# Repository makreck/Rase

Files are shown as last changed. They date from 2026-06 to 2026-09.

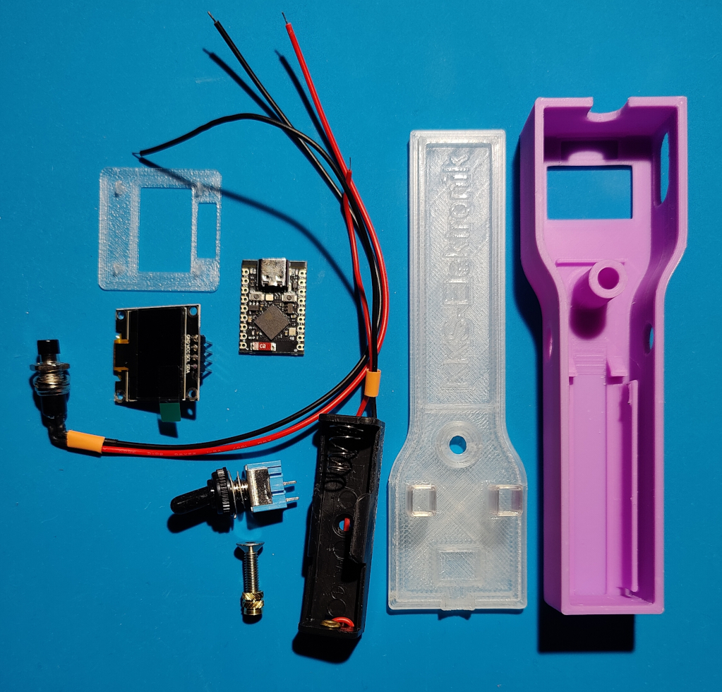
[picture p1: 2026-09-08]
images/probe/Type_C/Housings_Rev_C_Material_2.jpg

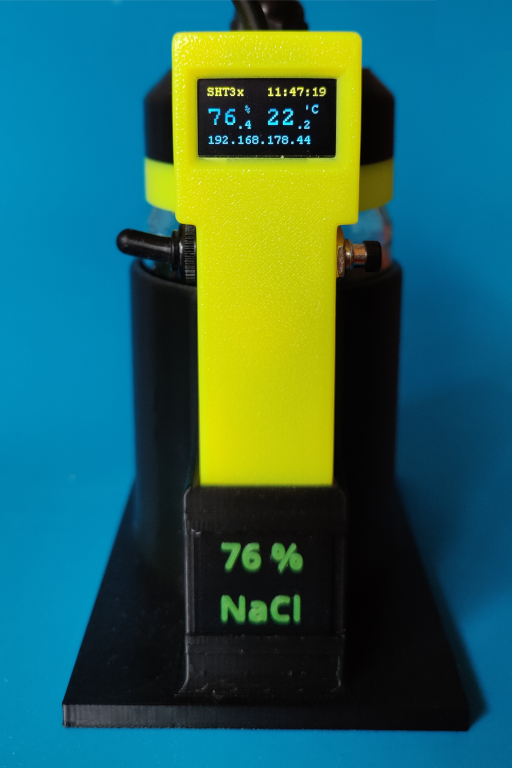
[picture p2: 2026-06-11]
images/calibration/Deliquescence_humidity_container_NaCl_76.png

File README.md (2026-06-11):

# Rase
## A Radio Sensor Project

### Disclaimer of Liability

This project is licensed under the terms of the GNU General Public License, version 3 or later (the "License"). A copy of the license is included in the root directory of this repository, and can also be found at "https://www.gnu.org/licenses/gpl-3.0.en.html".

This project is provided "as is", as open-source software and hardware, and is intended for hobbyist and enthusiast use, without warranties of any kind, either express or implied. The authors and contributors disclaim all liability for any damages or losses arising from the use or inability to use this project, including but not limited to direct, indirect, incidental, special, or consequential damages.

You are solely responsible for:
- Ensuring compliance with local laws and regulations when using this project.
- Any modifications or adaptations made to the hardware, firmware, or software.
- The safe and proper operation of any devices built using this project.
- Compliance with applicable licensing terms (e.g., GPL, MIT).

No warranties are given regarding:
- The accuracy, reliability, or suitability of the project for any purpose.
- The absence of errors or defects in the code, documentation, or hardware designs.
- Compatibility with third-party software or hardware.
- Build guides and documentation are provided for informational purposes. The authors do not guarantee correctness, completeness, or suitability for any specific purpose.

By using this project, you acknowledge and agree to these terms.

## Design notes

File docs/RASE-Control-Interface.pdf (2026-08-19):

# RASE Sensor Control Interface

## RESTful interface, endpoints over HTTP:

"/" | HTTP GET | Root website.
"/config" | HTTP GET | Configuration website.
"/update" | HTTP GET | Update website.
"/favicon.ico" | HTTP GET | Favicon request.
"/api/sensors" | HTTP GET | Query currently sensor status, returns JSON string.
"/api/id" | HTTP GET | Query device identifivation, returns JSON string.
"/api/config" | HTTP GET HTTP PUT | Query device configuration, return JSON string. Write device configuration, writes back JSON string.
"/api/reboot" | HTTP GET | Causes device reboot. Returns status JSON string.
"/api/update" | HTTP PUT | Receives new firmware image (binary).

## Terminal interface, endpoints over TTY:

"/root" | Returns HTTP source of root website.
"/connect" | Configures WiFi conection, format: „/connect=Wifi-SSID:password“
"/broker" | Configures MQTT broker, format: /broker=IP-addr[:username[:password]]“
"/par" | Set a single config parameter. Allowed keys are all keys of config JSON string. Format: „/par=key:value“
"/api/sensors" | Query currently sensor status, returns JSON string.
"/api/id" | Query device identifivation, returns JSON string.
"/api/config" | Query device configuration, return JSON string.
„/api/config=“ | Write device configuration, writes back JSON string. Parameter = config JSON.
"/api/reboot" | Forces an immediate device reboot.
"/api/initialize" | Forces a factory init. All condfig parameter are set to their defaults.

## Root website layout (example):

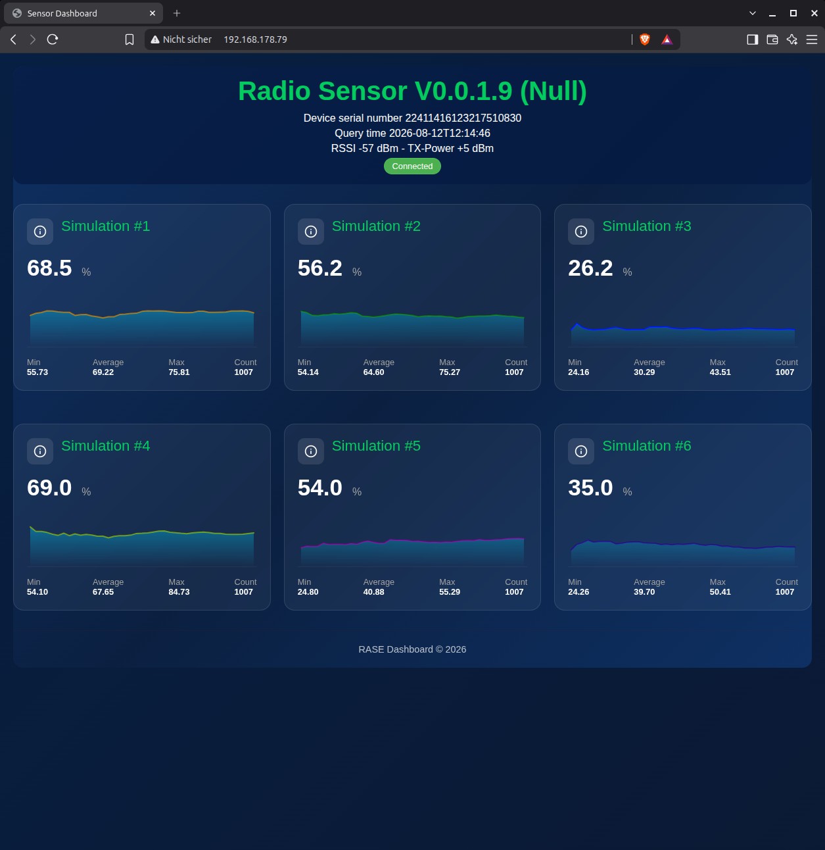
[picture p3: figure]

## Config website (example):

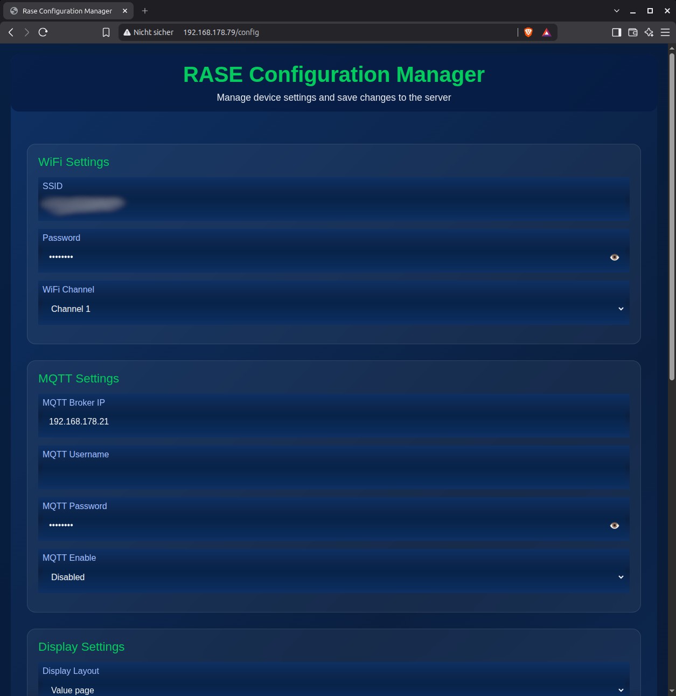
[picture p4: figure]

## Update website (example):

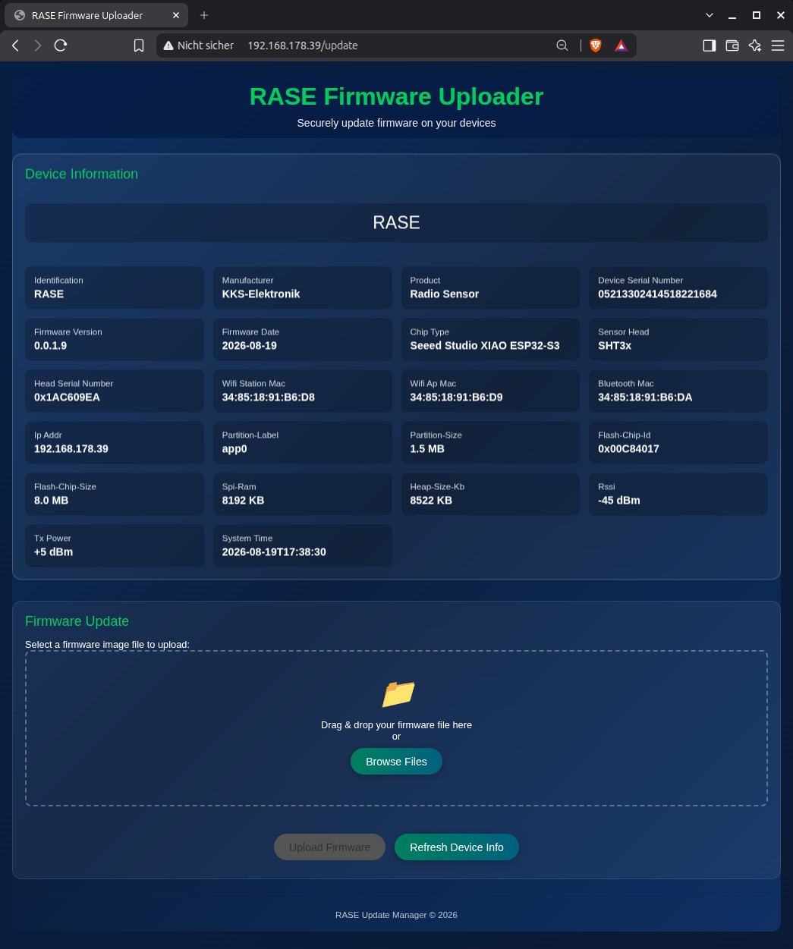
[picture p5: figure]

## Sensor status JSON (example):

{
"sensor": "Radio Sensor V0.0.1.9 (Null)", "device_serial_number": "22411416123217510830", "timestamp": "2026-08-12T12:01:52",
"rssi": "-57 dBm",
"tx_power": "+5 dBm",
"channels": 6,
"nodes": [
{ "sim_1": {
"name": "Simulation #1",
"shortcut": "X1",
"unit": "%",
"color": "#bb6a00",
"bottom": 0.000,
"top": 100.000,
"value": 61.514,
"min": 59.086,
"max": 78.542,
"average": 69.963,
"flags": 33,
"count": 1692,
"history": [ 78.5, 65.3, 73.2, 74.2, 69.3, 71.0, 71.8, 72.6, 68.0, 70.5, 68.1, 69.0, 68.7, 73.2, 72.5, 73.5, 74.9, 74.5, 75.0, 73.2, 70.3, 68.9, 71.8, 74.8, 73.3, 72.2, 68.4, 70.4, 71.6, 73.9, 74.5, 73.7, 72.6, 72.7, 70.5, 68.1, 68.5, 66.7, 65.9, 65.9, 64.9, 65.6, 67.7, 69.0, 69.6, 69.4, 67.2, 66.1, 66.9, 68.7, 68.3, 66.4, 65.0, 62.2 ] }
},
{ "sim_2": {
"name": "Simulation #2",
"shortcut": "X2",
"unit": "%",
"color": "#126e00",
"bottom": 0.000,
"top": 100.000,
"value": 34.783,
"min": 15.922,
"max": 42.184,
"average": 31.211,
"flags": 33,
"count": 1692,
"history": [ 16.4, 25.9, 31.7, 30.2, 26.1, 35.2, 35.6, 34.2, 34.9, 37.6, 40.0, 37.7, 34.9, 35.9, 32.7, 30.6, 32.7, 37.7, 40.8, 37.9, 35.4, 35.1, 35.7, 34.9, 29.8, 30.9, 34.5, 34.8, 35.8, 35.9, 36.6, 35.2, 31.2, 29.4, 29.7, 28.9, 28.1, 26.0, 25.4, 25.7, 26.9, 26.4, 25.8, 26.5, 28.3, 28.1, 28.1, 28.5, 29.3, 30.0, 31.5, 32.9, 32.4, 34.2 ] }
}
]
}

## Device identification JSON (example):

{
"identification": "RASE",
"manufacturer": "KKS-Elektronik",
"product": "Radio Sensor", "device_serial_number": "04804824902214116000", "firmware_version": "0.0.1.9",
"firmware_date": "2026-08-19",
"chip_type": "ESP32-S3 Wroom",
"sensor_head": "SHT3x",
"head_serial_number": "0x1AEB1E21", "wifi_station_mac": "30:30:F9:16:8D:A0", "wifi_ap_mac": "30:30:F9:16:8D:A1", "bluetooth_mac": "30:30:F9:16:8D:A2", "ip_addr": "192.168.178.52", "partition-label": "app1", "partition-size": "1.5 MB", "flash-chip-id": "0x005E4018", "flash-chip-size": "8.0 MB", "spi-ram": "8192 KB",
"heap-size-kb": "8520 KB",
"rssi": "-42 dBm",
"tx_power": "+5 dBm",
"system_time": "2026-08-19T16:39:22" }

## Config JSON (example):

{
"version": "0x20260710",
"ssid": "YOUR SSID",
"password": "YOUR PASSWORD", "wifi_channel": "1",
"mqtt_broker": "192.168.178.21", "mqtt_username": "YOUR MQTT USERNAME", "mqtt_password": "YOUR MQTT PASSWORD", "mqtt_enable": "disabled",
"display_layout": "Value page",
"display_param": "0",
"display_rotation": "0°",
"display_timeout": "Never",
"display_contrast": "10%",
"sensor_type": "autoscan,autoscan,Null,SHT2x,SHT3x,HTU21d,ATHxx,HDC1080,BMx280", "led_intensity": "1%"
}

## Reboot status JSON (example):

{
"device_serial_number": "22411416123217510830", "reboot_time_stamp": "2026-08-12T12:06:15"
}

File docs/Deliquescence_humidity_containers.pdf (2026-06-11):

## Deliquescence Humidity Test-containers

(Please observe the respective hazard warnings!)

The sensor accuracy can be checked using deliquescence humidity containers. These containers hold a saturated salt solution, over whose surface an equilibrium humidity is established. Various relatively harmless household salts and other substances, such as water and desiccants, can be used:

H₂O (dihydrogen monoxide, destilated water) results in 100% relative humidity.

NaCl (sodium chloride, table salt) results in 76% relative humidity.

K₂CO₃ (potassium carbonate, potash) results in 43% relative humidity (slight deviation in testing).

MgCl₂ (magnesium chloride, bath salts) results in 34% relative humidity.

LiCl (lithium chloride, desiccant) results in 11% relative humidity (not tested due to high cost).

CaCl₂ (dried calcium chloride, desiccant) results in 0–3% relative humidity.

All substances used are readily available and either already present in the household (water, table salt) or can be ordered, for example, from Amazon.

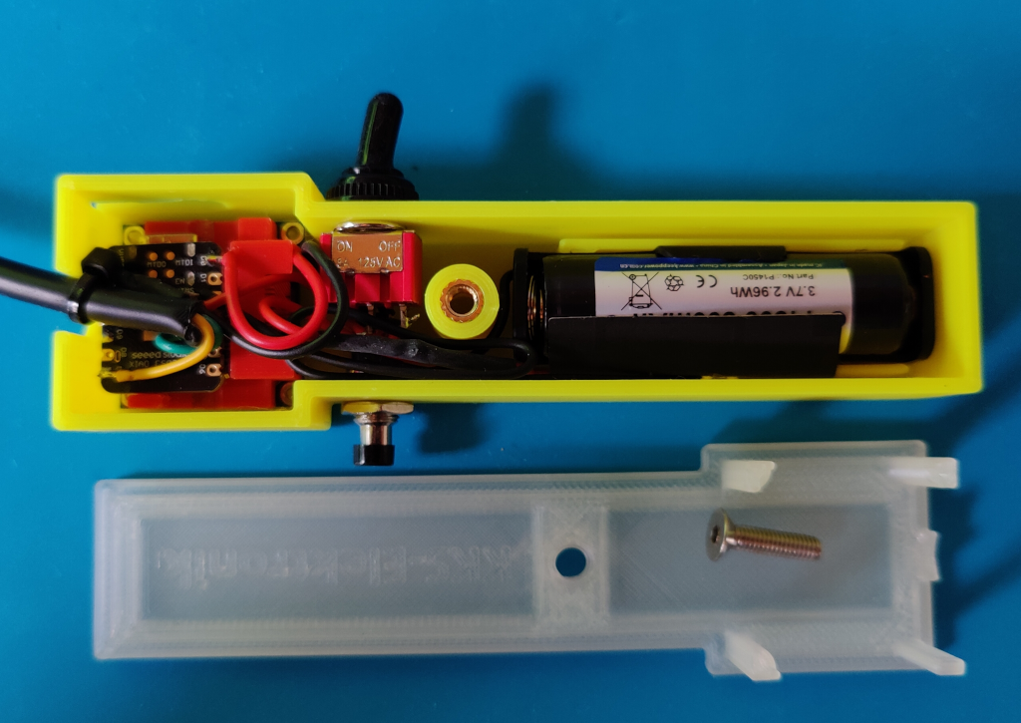
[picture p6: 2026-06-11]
images/probe/Type_B/Handheld_measuring_probe_02.png

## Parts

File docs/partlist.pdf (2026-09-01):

# Part list for handheld probe

- - 1 x Seeed Studio XIAO ESP32-S3 (8MB Flash, 8MB SPI-RAM) or ESP32-S3 Super Mini (4MB Flash, 2 MB SPI-RAM) with battery charging support.
(https://www.amazon.de/dp/B0BYSB66S5, https://www.amazon.de/dp/B0FKH1F8VV, https://eckstein-shop.de/Seeed-Studio-XIAO-ESP32S3-Dual-Core-24GHz-Wi-Fi-BLE50-Battery-Charge-Supported) (https://eckstein-shop.de/Seeed-Studio-XIAO-ESP32S3-Dual-Core-24GHz-Wi-Fi-BLE50-Battery-Charge-Supported)
- - 1 x „Golden Morning Electronic“ GME 12864-11-12-13, 0,96'', 27.42 x 27.85 mm, OLED SSD1306 I2C display module, 128 x 64 pixels twin-color, blue or white. With housing rev. C also a similar 0.96 Inch OLED display with a little bit different mounting holes and board sizes. Important: Pin order must be "GND,VCC,SCL,SDA". The firmware supports SSD1306 and SH1106 display controllers, or compatible types, with 128 by 64 pixels visible resolution.
(https://www.amazon.de/dp/B0BWJFVYZR, https://www.amazon.de/dp/B0D2P4J1R6, https://www.amazon.de/dp/B0F13SZ757,https://www.amazon.de/dp/B0F13QRNM3)
- - 1 x SPST Button Switch, 6 mm Head, 7.2 mm thread, innner height 8.5 mm, outer height 12.8 mm or near. (https://www.amazon.de/dp/B088WQFBDR)
- - 1 x MTS-101 mini toggle switch, ON/OFF.
(https://www.amazon.de/dp/B07SBQ6TS3 or https://www.amazon.de/dp/B07JPDMGX4)
- - 1 x Keeppower 14500 - 1100 mAh, 3,6-3,7V Li-Ion battery PCB protected P1450C3, or similar type. (https://www.akkuteile.de/lithium-ionen-akkus/14500/keeppower/keeppower-14500-1100-mah-3-6-3-7v-li-ion-akku-pcbgeschuetzt-p1450c3_12073_2785) (https://www.akkuteile.de/lithium-ionen-akkus/14500/keeppower/keeppower-14500-1100-mah-3-6-3-7v-li-ion-akku-pcb-geschuetzt-p1450c3_12073_2785)
- - 1 x Battery holder AA (14500), width 17 mm, length 60 mm, height 15 mm.
(https://www.amazon.de/dp/B08Z32KMHN)
- - 1 x Sensor module (supported types: SHT2x/HTU21d/BME280/BME280/HDC1080/ATH10/ATH21) with I2C interface. e.g. ready to use FS200, FS304 or FS400 modules.
(https://www.amazon.de/dp/B0C6L73L8S, https://www.amazon.de/dp/B07X33M2DK, https://www.amazon.de/dp/B0FJHZ7387,https://www.amazon.de/dp/B0H83PVXF9, https://www.amazon.de/dp/B0DSVMSZ3L,https://www.amazon.de/dp/B0CLS3NB4Q)
- - 1 x M4 press-fit nut.
(https://www.amazon.de/dp/B0CRHK8P9P)
- - 1 x M4 x 16 mm countersunk screw (https://www.amazon.de/GUEEYUAW-Senkkopfschrauben-Edelstahl-Senkkopf-Innensechskant/dp/B0FLQF2CG8)

Note: There are existing also 0,96'' OLED display boards with the not usable "VCC,GND,SCL,SDA" order. To connect the display directly on the top of the ESP32-S3 board (5V, GND, 3V, GPIO, GPIO), we need GND 1st and then VCC !

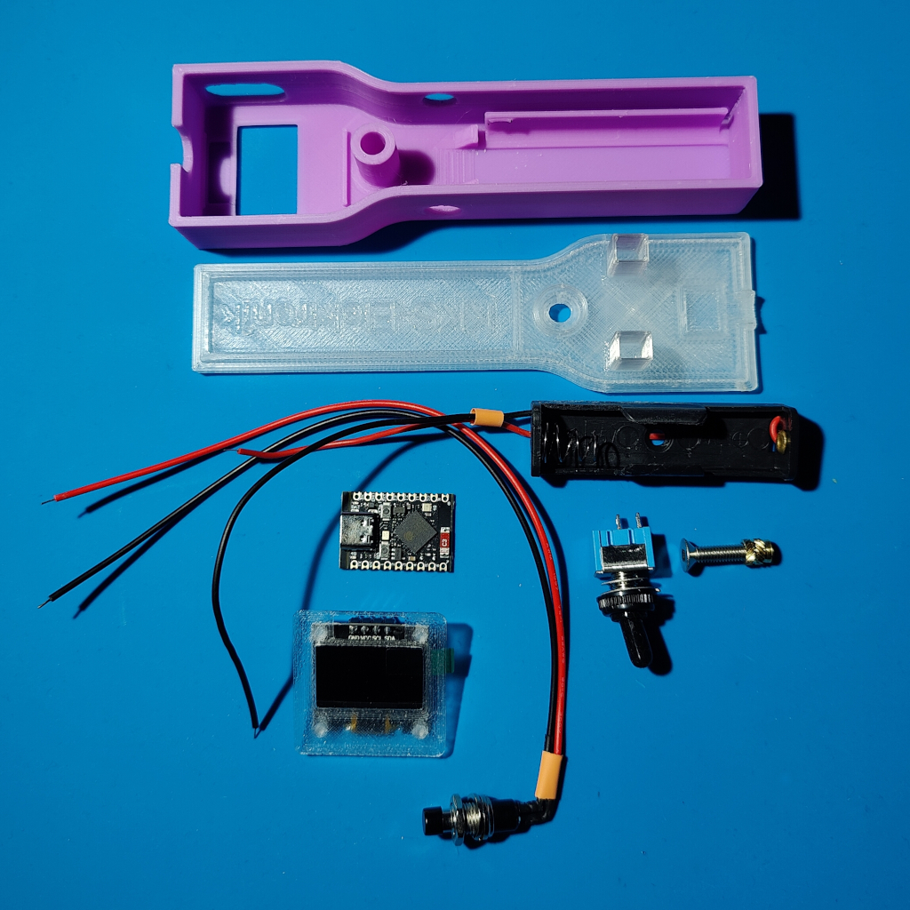
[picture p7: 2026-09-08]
images/probe/Type_C/Housings_Rev_C_Material.jpg

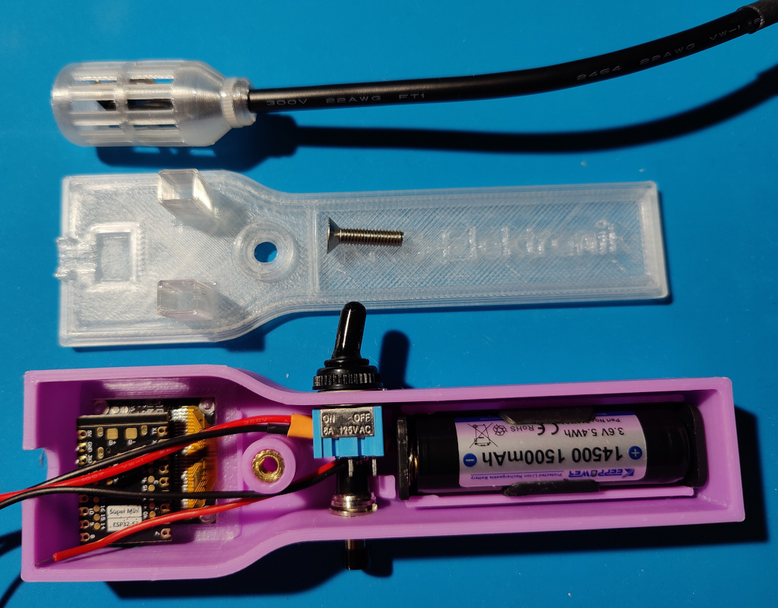
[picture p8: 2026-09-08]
images/probe/Type_C/Housings_Rev_C_Parts.jpg

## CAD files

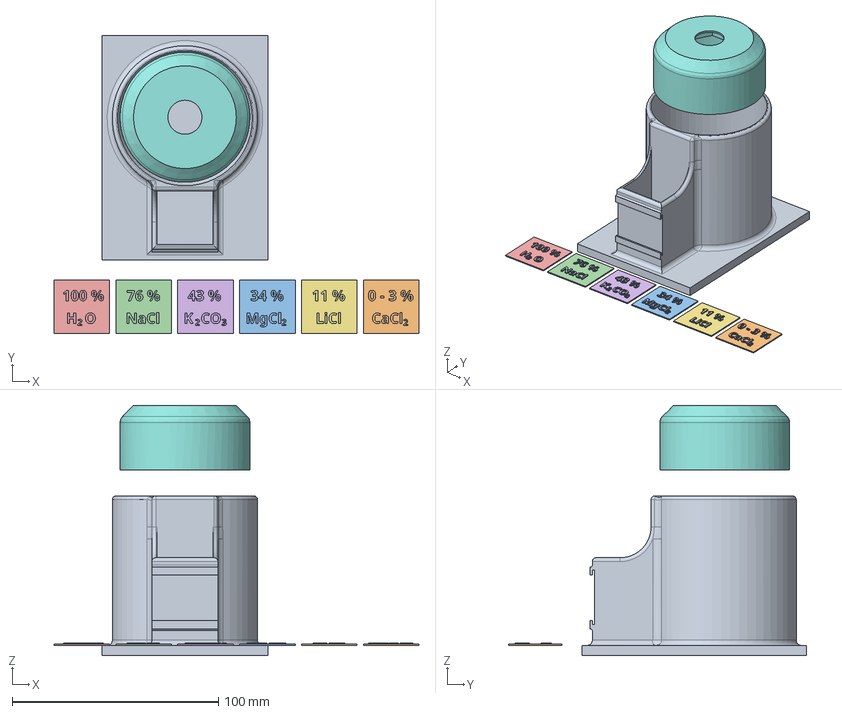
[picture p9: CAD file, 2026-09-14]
mechanical/glas-cradle/OneGlasCradle.FCStd
177.0 x 144.8 x 121.4 mm
Glas
Plate_3_percent
Plate_34_percent
Plate_76_percent
Plate_100_percent
Plate_43_percent
Plate_11_percent
Hood

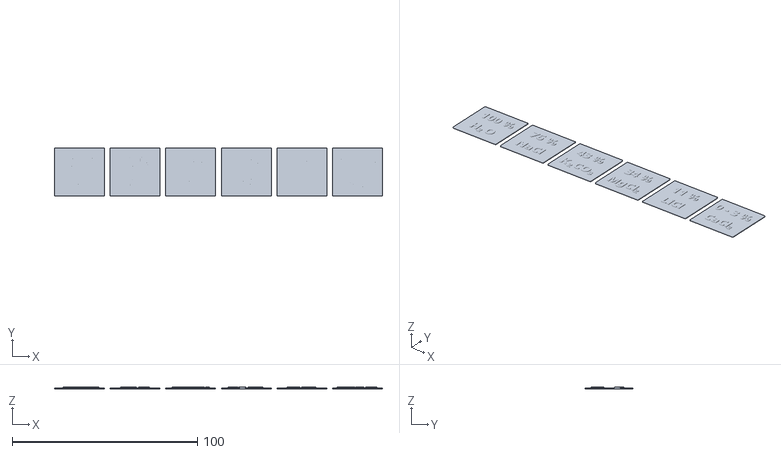
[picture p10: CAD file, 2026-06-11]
mechanical/glas-cradle/STL/OneGlasCradle-Plates.stl
177.0 x 26.0 x 1.20

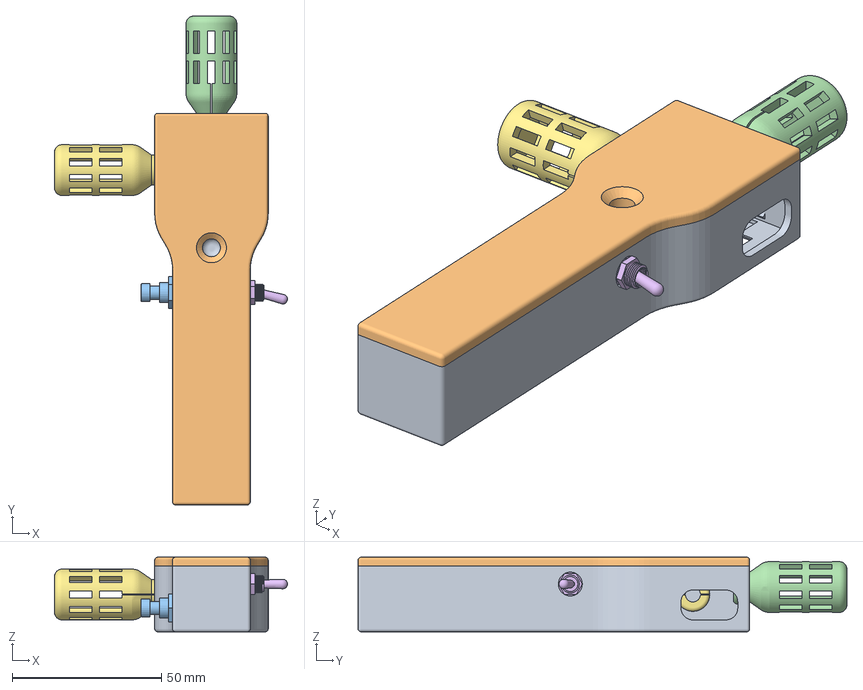
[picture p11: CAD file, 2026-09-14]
mechanical/housing/Rev_C/MultiType_Housing_Rev_C.FCStd
77.9 x 163.5 x 25.0 mm
Top_14500
PushButton_14500
Sensor_Cover_14500
BatteryHolder_AA_14500
Toggleswitch
Sensor_Cover_No_Battery

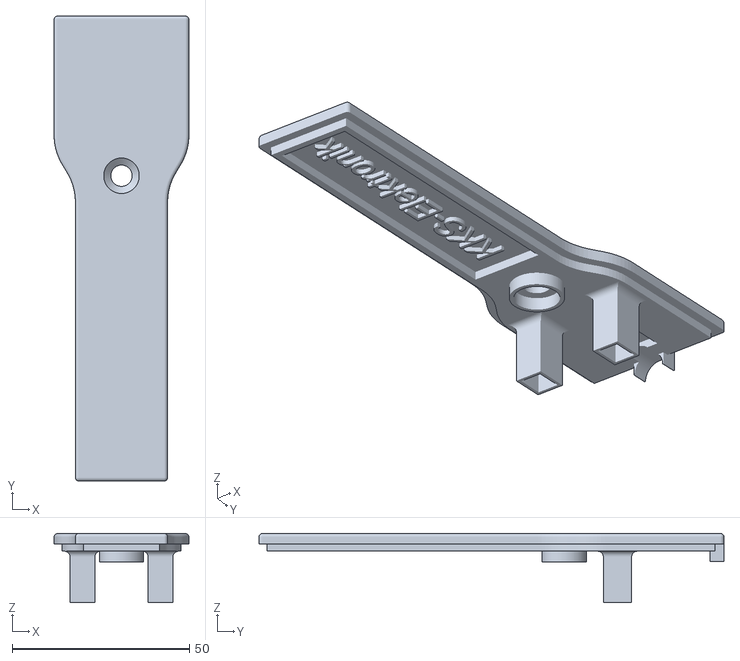
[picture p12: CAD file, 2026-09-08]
mechanical/housing/Rev_C/STL/MT_Top_14500.stl
38.0 x 131.0 x 19.5

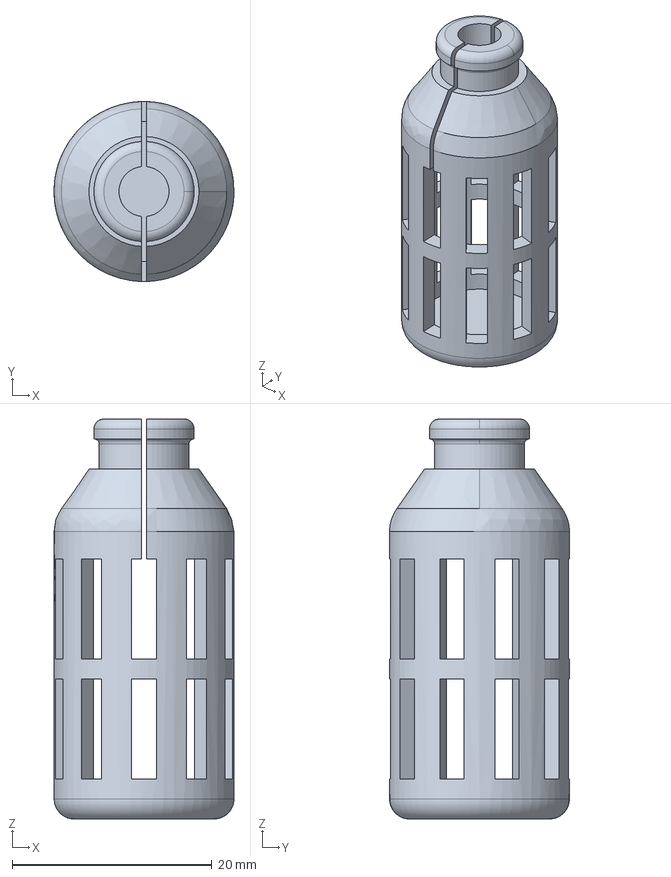
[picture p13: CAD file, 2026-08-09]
mechanical/Sensor/TPU_SensorCover.FCStd
18.0 x 18.0 x 40.0 mm

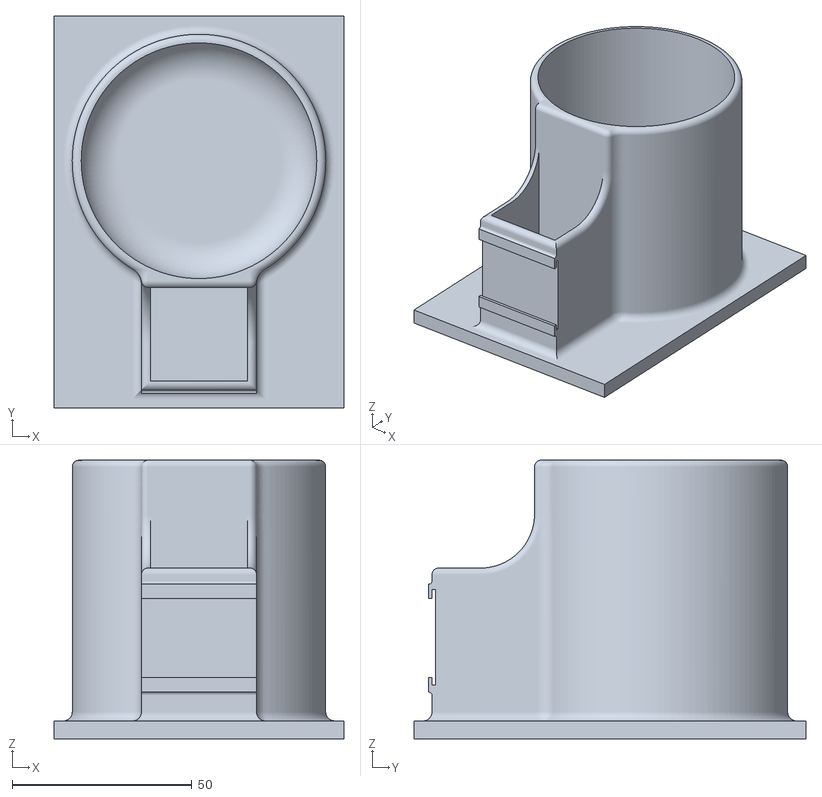
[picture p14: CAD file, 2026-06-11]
mechanical/glas-cradle/STL/OneGlasCradle-Glas.stl
80.5 x 109.0 x 77.5

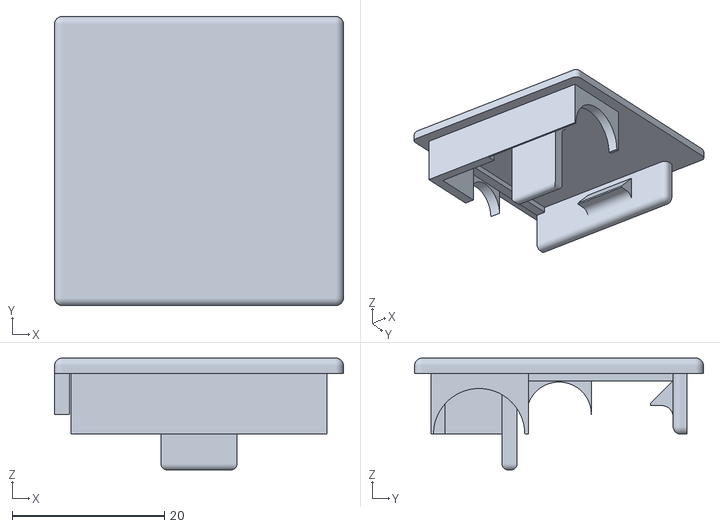
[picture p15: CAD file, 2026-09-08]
mechanical/housing/Rev_C/STL/MT_Top_Batless.stl
38.0 x 38.0 x 14.7

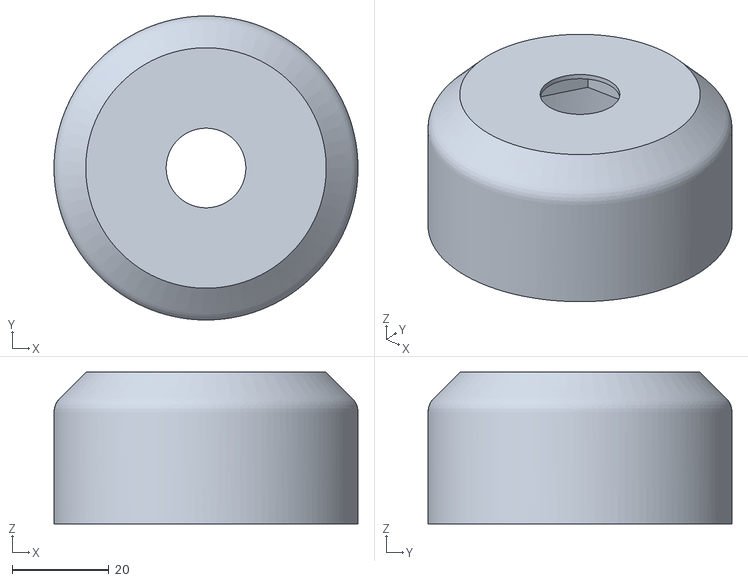
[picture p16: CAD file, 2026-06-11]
mechanical/glas-cradle/STL/OneGlasCradle_Hood.stl
63.0 x 63.0 x 31.4

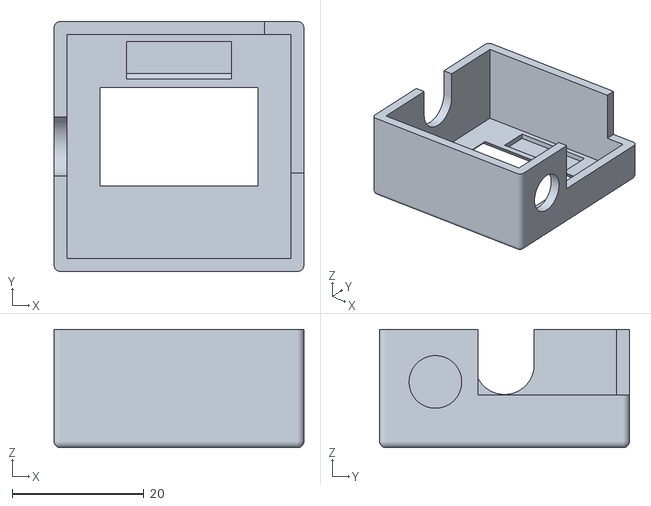
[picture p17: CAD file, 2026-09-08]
mechanical/housing/Rev_C/STL/MT_Body_Batless.stl
38.0 x 38.0 x 18.0

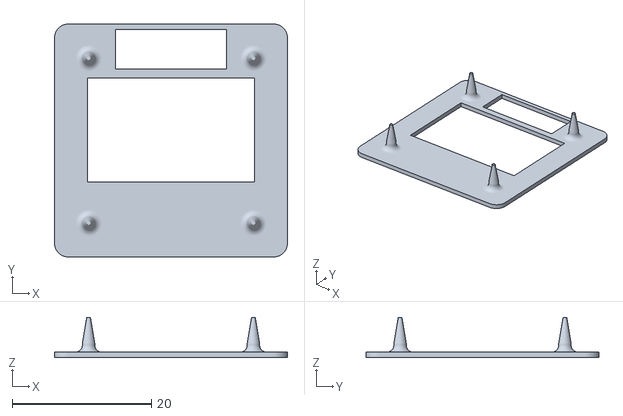
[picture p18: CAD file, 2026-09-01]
mechanical/housing/Rev_C/STL/MT_Display_Plate_Type_A.stl
33.5 x 33.5 x 5.80

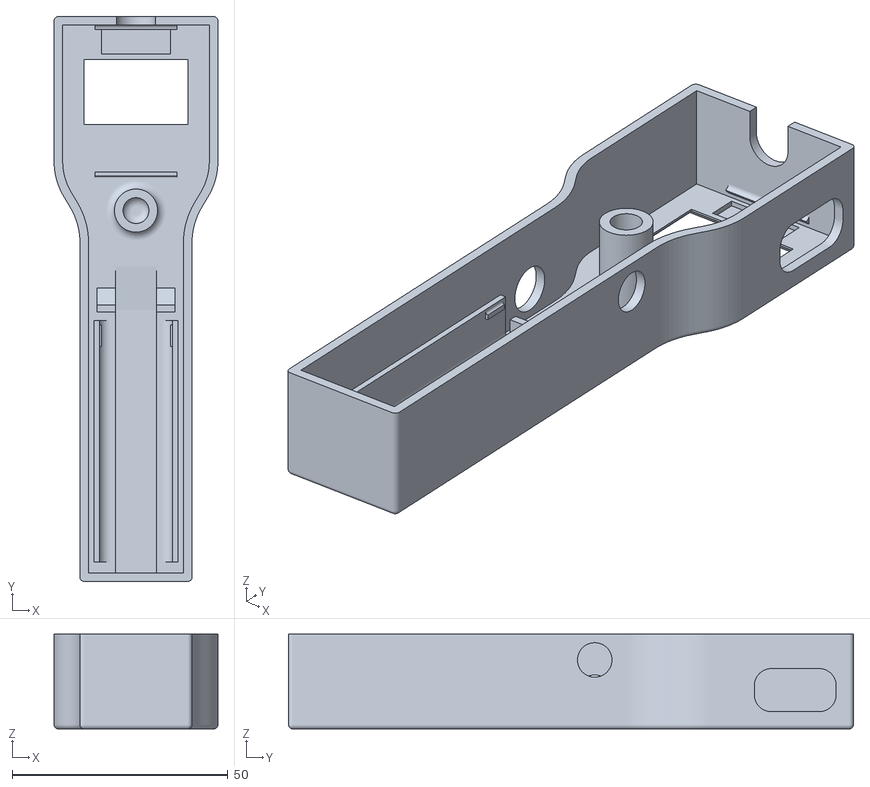
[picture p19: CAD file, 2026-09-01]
mechanical/housing/Rev_C/STL/MT_Body_14500.stl
38.0 x 131.0 x 22.0

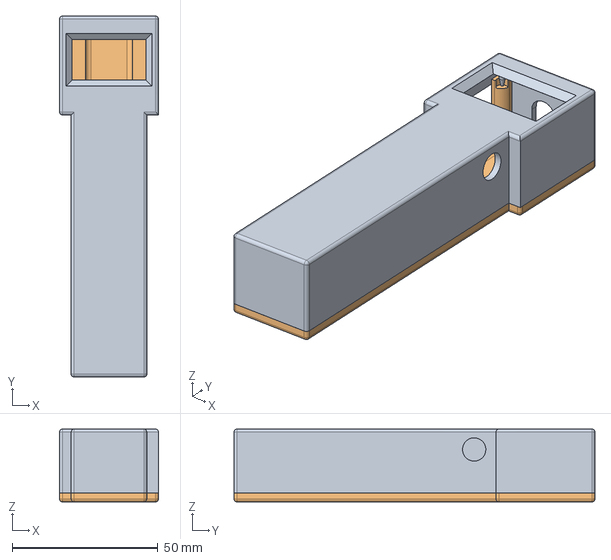
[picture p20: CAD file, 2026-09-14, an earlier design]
mechanical/housing/Rev_B/SeeedStudio_XIAO_ESP32S3_Housing.FCStd
34.0 x 124.0 x 25.0 mm
Body_base
Cover_base

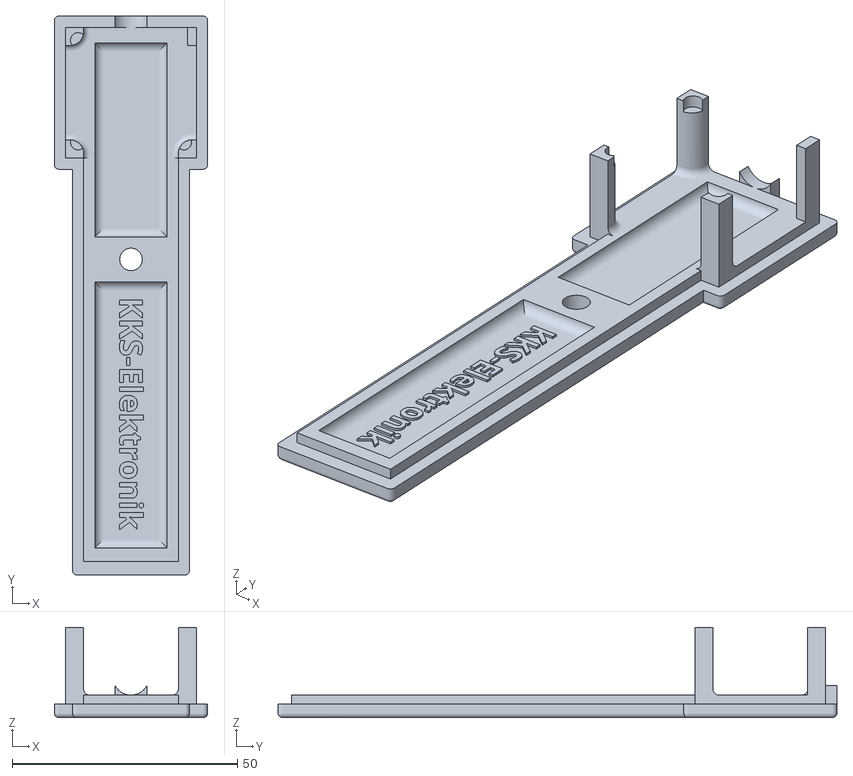
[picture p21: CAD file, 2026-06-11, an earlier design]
mechanical/housing/Rev_B/STL/SeeedStudio_XIAO_ESP32S3_Housing_Cover.stl
34.0 x 124.0 x 20.0

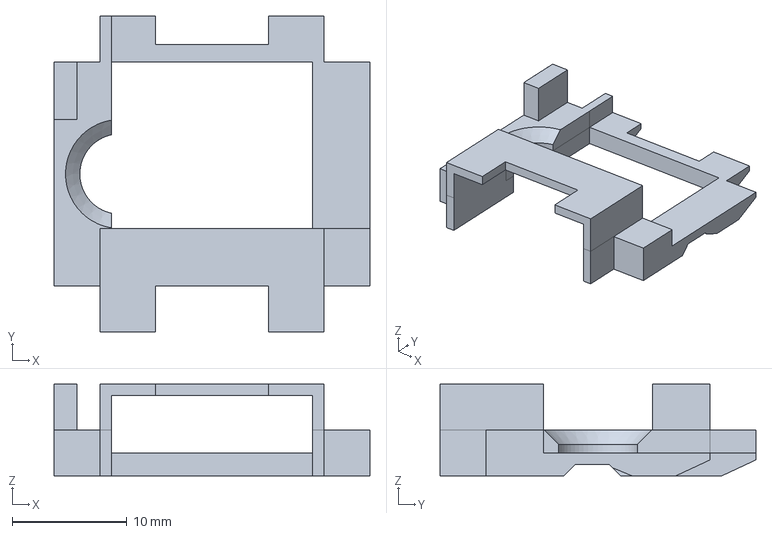
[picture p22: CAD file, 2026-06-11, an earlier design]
mechanical/housing/Rev_B/SeeedStudio_XIAO_ESP32S3_BoardHolder.FCStd
27.5 x 27.5 x 8.00 mm

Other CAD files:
mechanical/housing/Rev_C/STL/MT_Display_Plate_Type_C.stl
mechanical/housing/Rev_C/STL/MT_Display_Plate_Type_B.stl
mechanical/housing/Rev_B/STL/SeeedStudio_XIAO_ESP32S3_Housing_Body.stl
mechanical/housing/Rev_B/STL/SeeedStudio_XIAO_ESP32S3_BoardHolder-Board_holder.stl
mechanical/Sensor/STL/TPU_Sensor_Cover.stl

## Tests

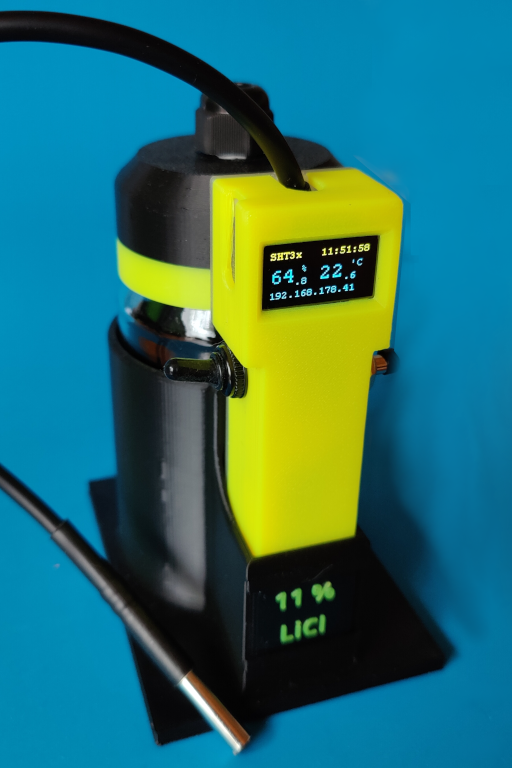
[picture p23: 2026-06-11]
images/calibration/Deliquescence_humidity_container_LiCl_11.png

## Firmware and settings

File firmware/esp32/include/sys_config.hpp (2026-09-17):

/*
 * ==============================================================================
 *
 *  PROJECT:     "Rase" Radio Sensor Project,    ESP32-S3 Station Device Firmware
 *  COPYRIGHT:   (C)2025-2026 KKS-Elektronik,  M. Kreck, <makreck@googlemail.com>
 *
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
 * ==============================================================================
 */

#pragma once

#define WCFG_VERSION                 (0x20260710)
// #define WCFG_VERSION                 (0x20260701)
// #define WCFG_VERSION                 (0x20260410)

#define WCFG_STORAGE_NAMESPACE       SENSOR_ID
#define WCFG_STORAGE_CONFIG_KEY      "system-config"

#define LED_INTENSITY_MAX            (1.00f)
#define LED_INTENSITY_HIGH           (0.75f)
#define LED_INTENSITY_MEDIUM         (0.50f)
#define LED_INTENSITY_LOW            (0.25f)
#define LED_INTENSITY_VERY_LOW       (0.05f)
#define LED_INTENSITY_MIN            (0.01f)
#define LED_INTENSITY_OFF            (0.00f)
#define LED_DEFAULT_INTENSITY        (LED_INTENSITY_VERY_LOW)

#if defined ESP32_S3_ZERO
    #define LED_DEFAULT_COLOR_ORDER (ColorOrder::BGR)
#elif defined ESP32_S3_WROOM_1 || defined ESP32_WROOM_DEV || defined ESP32_WROVER_DEV || defined ESP32_S3_SUPER_MINI
    #define LED_DEFAULT_COLOR_ORDER (ColorOrder::BRG)
#else
    #define LED_DEFAULT_COLOR_ORDER (ColorOrder::RGB)
#endif

#define DISPLAY_CONTRAST_DEFAULT     (0.80f)

#define DEFAULT_IFC_ENABLE           (true)
#define DEFAULT_MQTT_ENABLE          (false)

#ifdef ESP32_S3_WROOM_1
    #define DISPLAY_ROTATION_DEFAULT (180)
#else
    #define DISPLAY_ROTATION_DEFAULT (0)
#endif

#define WIFI_DEFAULT_CHANNEL         (1)
#define WIFI_MAX_CONNECTION          (10)

// *** Misc default data, later to be defined in their modules:
#define T_APP_DISPLAY_TIMEOUT_S      (0.0f)
#define DISPLAY_LAYOUT_DEFAULT       (DisplayLayout::large_values)
#define SENSOR_TYPE_DEFAULT          (SensorType::autoscan)

#define WIFI_AP_NAME_MAX             (32)
#define WIFI_AP_PASSWD_MAX           (64)
#define MQTT_BROKER_MAX              (64)
#define MQTT_USERNAME_MAX            (32)
#define MQTT_PASSWORD_MAX            (32)

enum class DisplayLayout {
    large_values = 0,
    detailes     = 1,
    info         = 2,
};

class SysConfigData {
    public:
        union {
            struct {
                uint32_t version;
                char ssid[WIFI_AP_NAME_MAX];
                char password[WIFI_AP_PASSWD_MAX];
                char mqtt_broker[MQTT_BROKER_MAX];
                char mqtt_username[MQTT_USERNAME_MAX];
                char mqtt_password[MQTT_PASSWORD_MAX];
                uint8_t wifi_channel;
                uint8_t sensor_type;
                uint8_t display_layout;
                uint8_t display_param;
                uint8_t color_order;
                uint8_t reserved1[2];
                union {
                    uint8_t flags;
                    struct {
                        uint8_t f_display_rotoation : 2;
                        uint8_t f_ifc_enable        : 1;
                        uint8_t f_mqtt_enable       : 1;
                        uint8_t f_reserved          : 4;
                    };
                };

                float display_timeout_s;
                float led_intensity;
                float display_contrast;
            };
            uint8_t data[256];
        };
};

class SysConfig;

class JsonScan {
    public:
        const char* key;
        AppState (*scan_function)(SysConfig*, const char *);
};

class SysConfig {
    private:
        static const char* config_json_format;
        static const char* str_display_layout[3];
        static const JsonScan config_scan_table[];

        SysConfigData cfg;
        bool modified = false;
        char format[32]{ 0 };

    public:
        SysConfig(void) {
            init();
        }
        
        ~SysConfig() {
            cleanup();
        }

        void print_parms(const char* hint = nullptr);

        static AppState get_mac_Address(char* string, size_t size);
        static const char* get_display_layout_name(DisplayLayout __layout);
        
        AppState init(void);
        AppState cleanup(void);
        AppState load_defaults(void);
        AppState init_nvs_flash(bool forceInit = false);
        AppState check(void);
        AppState load(void);
        AppState save(void);
        AppState update(void);
        AppState perform_factory_reset(void);

        AppState set_wifi_channel(int _channelNumber);
        AppState set_display_timeout(float _timeout_s);
        AppState set_display_rotation(int _degrees);
        AppState set_display_contrast(float _value);
        AppState set_display_layout(DisplayLayout layout);
        AppState set_display_parameter(int _parameter = 0);
        AppState set_ssid(const char* _ap_name);
        AppState set_password(const char* _password);
        AppState set_mqtt_broker(const char* _broker);
        AppState set_mqtt_username(const char* _username);
        AppState set_mqtt_password(const char* _password);
        AppState set_mqtt_enable(bool enable);
        AppState set_sensor_type(SensorType _type);
        AppState set_LED_intensity(float _intensity);
        AppState set_LED_color_order(ColorOrder _color_order);

        static AppState set_wifi_ssid_str(SysConfig* _instance, const char* _ap_name);
        static AppState set_wifi_password_str(SysConfig* _instance, const char* _password);
        static AppState set_wifi_channel_str(SysConfig* _instance, const char* _channel);

        static AppState set_mqtt_broker_str(SysConfig* _instance, const char* _broker);
        static AppState set_mqtt_username_str(SysConfig* _instance, const char* _username);
        static AppState set_mqtt_password_str(SysConfig* _instance, const char* _password);

        static AppState set_display_rotation_str(SysConfig* _instance, const char* _degrees);
        static AppState set_display_contrast_str(SysConfig* _instance, const char* _value);
        static AppState set_display_timeout_str(SysConfig* _instance, const char* _str);
        static AppState set_display_layout_str(SysConfig* _instance, const char* _layout);
        static AppState set_display_parameter_str(SysConfig* _instance, const char* _parameter);
        static AppState set_mqtt_enable_str(SysConfig* _instance, const char* _enable);
        static AppState set_sensor_type_str(SysConfig* _instance, const char* _type);
        static AppState set_LED_intensity_str(SysConfig* _instance, const char* _intensity);
        static AppState set_LED_color_order_str(SysConfig* _instance, const char* _color_order);
        
        const char* get_ssid(void);
        const char* get_password(void);
        const char* get_mqtt_broker(void);
        const char* get_mqtt_username(void);
        const char* get_mqtt_password(void);
        const char* get_display_timeout_str(void);
        const char* get_display_layout_str(void);
        const char* get_color_order_str(void);
                
        float get_display_timeout(void);
        float get_LED_intensity(void);
        ColorOrder get_LED_color_order(void);
        float get_display_contrast(void);
        AppState import_json(const char* _json_string, size_t _length);
        char* get_json(bool _hide_passwords, bool _sensor_list);
        DisplayLayout get_display_layout(void);
        uint8_t get_display_parameter(void);
        int get_wifi_channel(void);
        int get_display_rotation(void);
        AppState flip_display_rotation(void);
        SensorType get_sensor_type(void);
        bool get_config_enable(void);
        AppState set_config_enable(bool enable);
        bool get_mqtt_enable(void);
};

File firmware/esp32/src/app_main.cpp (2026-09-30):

/*
 * ==============================================================================
 *
 *  PROJECT:     "Rase" Radio Sensor Project,    ESP32-S3 Station Device Firmware
 *  COPYRIGHT:   (C)2025-2026 KKS-Elektronik,  M. Kreck, <makreck@googlemail.com>
 *
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
 * ==============================================================================
 */

#include "app.hpp"

// #define DISPLAY_STATE

AppState App::init(void) {
    init_power();
    init_memory();
    init_watchdog();
    init_event_loop();

    init_buttons();
    init_config();
    init_LEDs();
    init_display();
    init_sdcard();
    init_wifi();
    init_driver();
    init_webserver();
    init_mqtt();

    return (AppState::OK);
}

AppState App::init_power(void) {
    esp_pm_config_t pm_config = {
        .max_freq_mhz = POWER_MCU_FREQ_MAX_MHZ,
        .min_freq_mhz = POWER_MCU_FREQ_MIN_MHZ,
        .light_sleep_enable = true,
    };
    esp_pm_configure(&pm_config);

    esp_sleep_enable_timer_wakeup(POWER_UP_DELAY_US);
    esp_light_sleep_start();

    vTaskDelay(pdMS_TO_TICKS(POWER_UP_DELAY_MS));

    return (AppState::OK);
}

AppState App::cleanup(void) {
    m.exitApp = true;

    if (m.task_handle != nullptr) {
        vTaskDelete(m.task_handle);
        m.task_handle = nullptr;
    }

    SAFE_DELETE(m.mqtt);
    SAFE_DELETE(m.webserver);
    SAFE_DELETE(m.driver);
    SAFE_DELETE(m.sensor);
    SAFE_DELETE(m.station);
    SAFE_DELETE(m.sdc);
    SAFE_DELETE(m.display);
    SAFE_DELETE(m.led);
    SAFE_DELETE(m.cfg);
    SAFE_DELETE(m.button);

    esp_event_handler_unregister(APP_EVENT, ESP_EVENT_ANY_ID, &App::_app_event_handler);
    esp_task_wdt_deinit();

    return (AppState::OK);
}

AppState App::init_watchdog(void) {
#ifdef ENABLE_WATCHDOG
    esp_task_wdt_config_t wdt = {
        .timeout_ms     = TASK_WATCHDOG_TIMEOUT,
        .idle_core_mask = 0x03,
        .trigger_panic  = true,
    };
    esp_task_wdt_deinit();
    esp_task_wdt_init(&wdt);
    esp_task_wdt_add(nullptr);
#endif    
    return (AppState::OK);
}

AppState App::init_memory(void) {
    return (AppState::OK);
}

AppState App::init_config(void) {
    m.cfg = new SysConfig();
    if (m.cfg->get_config_enable()) {
        m.cmd = new ConfigInterface(this);
    }
    return ((m.cfg != nullptr) ? AppState::OK : AppState::failed);
}

AppState App::init_event_loop(void) {
    esp_event_loop_create_default();
    esp_err_t result = esp_event_handler_register(APP_EVENT, ESP_EVENT_ANY_ID, &App::_app_event_handler, this);
    AppState state = ((result == ESP_OK) ? AppState::OK : AppState::failed);
    return (state);
}

AppState App::init_buttons(void) {
#ifdef _ENABLE_BUTTON    
    m.button = new Button();
    return ((m.button != nullptr) ? AppState::OK : AppState::failed);
#else
    return (AppState::not_implemented);
#endif    
}

AppState App::init_sdcard(void) {
#ifdef _ENABLE_SD_CARD
    m.sdc = new SDCard();
#endif
    return (AppState::OK);
}

AppState App::init_wifi(void) {
    esp_netif_init();
    const char* ssid = m.cfg->get_ssid();
    const char* pwd = m.cfg->get_password();
    if (strlen(ssid) > 0) {
        m.station = new Wifi_Station(ssid, pwd);
    }
    return (((m.station != nullptr) ? AppState::OK : AppState::failed));
}

AppState App::init_webserver(void) {
    m.webserver = new WebServer();
    return ((m.webserver != nullptr) ? AppState::OK : AppState::failed);
}

AppState App::init_mqtt(void) {
    if (m.cfg->get_mqtt_enable()) {
#ifdef DISPLAY_STATE
        ESP_LOGI(TAG, "init_mqtt(): MQTT is enabled.");
#endif
        const char* broker = m.cfg->get_mqtt_broker();
        if (strlen(broker) > 0) {
#ifdef DISPLAY_STATE
            ESP_LOGI(TAG, "init_mqtt(): Start connection: Broker=\"%s\".", m.cfg->get_mqtt_broker());
#endif
            m.mqtt = new Mqtt(m.cfg->get_mqtt_broker(), m.cfg->get_mqtt_username(), m.cfg->get_mqtt_password());
        }
#ifdef DISPLAY_STATE
    } else {
        ESP_LOGI(TAG, "init_mqtt(): MQTT not enabled.");
#endif
    }
    return ((m.mqtt != nullptr) ? AppState::OK : AppState::failed);
}

AppState App::init_driver(void) {
    m.sensor = new SensorDevice("ESP32-S3");
#ifdef _ENABLE_I2C_SENSOR
    m.driver = SensorDriver::auto_scan(m.cfg->get_sensor_type());
#endif    
    return (((m.sensor != nullptr) && (m.driver != nullptr)) ? AppState::OK : AppState::failed);
}

AppState App::trigger_watchdog(void) {
    if (m.exitApp) {
        return AppState::exit;
    }
#ifdef ENABLE_WATCHDOG
    return ((esp_task_wdt_reset() == ESP_OK) ? AppState::OK : AppState::watchdog);
#else
    return (AppState::OK);
#endif
}

AppState App::switch_driver_to(uint8_t i2c_addr) {
    if ((m.driver == nullptr) || (m.sensor == nullptr)) {
        return (AppState::not_ready);
    }

    if (m.driver->get_device_address() == i2c_addr) {
        return (AppState::OK);
    }

#ifdef DISPLAY_STATE
    ESP_LOGI(TAG, "switch_driver_to(0x%-2.2X)", (unsigned int)i2c_addr);
#endif
    m.sensor->set_driver(nullptr);
    if (m.mqtt != nullptr) {
        m.mqtt->stop();
    }

    m.driver->suspend();
    m.flags.b.driver_ready = 0;
    SAFE_DELETE(m.driver);

    m.driver = SensorDriver::create_driver_by_address(i2c_addr);
    if (m.driver != nullptr) {
        m.sensor->set_driver(m.driver);
        if ((m.mqtt != nullptr) && (m.cfg->get_mqtt_enable() == true)) {
            m.mqtt->start(m.driver);
        }
    }

    return (AppState::OK);
}

AppState App::request_sys_config_update(void) {
    m.update_thr_time = Tools::get_tickcount64() + 100;
    m.flags.b.nvm_update_req = 1;
    return (AppState::OK);
}

AppState App::handle_config_changes(void) {
    if (m.flags.b.display_cfg_req == 1) {
        m.flags.b.display_cfg_req = 0;
        if (m.display != nullptr) {
            m.display->set_contrast(m.cfg->get_display_contrast());
            m.display->set_rotation(m.cfg->get_display_rotation());
            request_sys_config_update();
        }
    }

    if (m.flags.b.driver_cfg_req == 1) {
        m.flags.b.driver_cfg_req = 0;
        uint8_t i2c_addr = SensorDriver::get_bus_addr_by_type(m.cfg->get_sensor_type());
        switch_driver_to(i2c_addr);
        request_sys_config_update();
    }

    if (m.flags.b.led_cfg_req == 1) {
        m.flags.b.led_cfg_req = 0;
        if (m.led != nullptr) {
            m.led->set_color_order(m.cfg->get_LED_color_order());
        }
    }

    return (AppState::OK);
}

AppState App::handle_nvm_update(void) {
    if (m.flags.b.nvm_update_req == 1) {

        if (m.update_thr_time != 0) {
            if (Tools::get_tickcount64() < m.update_thr_time) {
#ifdef DISPLAY_STATE
            ESP_LOGI(TAG, "handle_nvm_update() -> delayed...");
#endif
                return (AppState::not_ready);
            }
            m.update_thr_time = 0;
        }

        reload_screensaver();

#ifdef DISPLAY_STATE
        ESP_LOGI(TAG, "handle_nvm_update() -> saving data...");
#endif
        m.flags.b.nvm_update_req = 0;
        m.cfg->update();
        vTaskDelay(pdMS_TO_TICKS(250));
#ifdef DISPLAY_STATE
        ESP_LOGI(TAG, "handle_nvm_update() -> Update finished.");
#endif
    }
    return (AppState::idle);
}

AppState App::handle_reboot_request(void) {
    if (m.flags.b.factory_init_req == 1) {
        m.flags.b.factory_init_req = 0;

        if (m.display != nullptr) {
            esp_event_post(APP_EVENT, (int32_t)AppEvent::display_lock, nullptr, 0, pdMS_TO_TICKS(1));
            int y = (m.cfg->get_display_rotation() == 0) ? 0 : 3;
            m.display->clear();
            m.display->setLogo();
            m.display->print(0, y, "Factory reset...");
            m.display->update();
            vTaskDelay(pdMS_TO_TICKS(750));
        }

        m.cfg->perform_factory_reset();
        vTaskDelay(pdMS_TO_TICKS(250));

        // cleanup();
        esp_restart();

        return (AppState::failed);
    }

    if (m.flags.b.reboot_req == 1) {
        
        if (m.display != nullptr) {
            esp_event_post(APP_EVENT, (int32_t)AppEvent::display_lock, nullptr, 0, pdMS_TO_TICKS(1));
            int y = (m.cfg->get_display_rotation() == 0) ? 0 : 3;
            m.display->clear();
            m.display->setLogo();
            m.display->print(0, y, "System reboot...");
            m.display->update();
            vTaskDelay(pdMS_TO_TICKS(1000));
        }

        cleanup();
        esp_restart();

        return (AppState::failed);
    }

    return (AppState::idle);
}

void App::_app_event_handler(void* arg, esp_event_base_t event_base, int32_t event_id, void* event_data) {
    (reinterpret_cast<App*>(arg))->app_event_handler(event_base, (AppEvent)event_id, event_data);
}
esp_err_t App::app_event_handler(esp_event_base_t event_base, AppEvent event_id, void* event_data) {
    switch (event_id) {
        case AppEvent::measuring_event: {
            if (m.sensor != nullptr) {
                m.sensor->update((SensorReading*)event_data);
                m.flags.b.driver_query = 1;
                m.display_request++;
            }
        } break;

        case AppEvent::web_query_event: {
            m.flags.b.website_query = 1;
        } break;

        case AppEvent::web_api_event: {
            m.flags.b.web_api_query = 1;
        } break;

        case AppEvent::button_event: {
            m.btnState.set((ButtonState*)event_data);
#ifdef DISPLAY_STATE
            ESP_LOGI(TAG, "Button event: msg=%d, multi=%d, ms_pressed=%d, ms_released=%d, ms_idle=%d", 
                m.btnState.button_message, m.btnState.press_count, (int)m.btnState.time_pressed_ms, (int)m.btnState.time_released_ms, (int)m.btnState.time_idle_ms);
#endif
        } break;

        case AppEvent::button_idle: {
            m.flags.b.button_event = 1;
        } break;

        case AppEvent::button_ready: {
            m.flags.b.button_ready = 1;
#ifdef DISPLAY_STATE
            ESP_LOGE(TAG, "AppEvent::button_ready");
#endif
        } break;

        case AppEvent::display_ready: {
            m.flags.b.display_ready = 1;
#ifdef DISPLAY_STATE
            ESP_LOGE(TAG, "AppEvent::display_ready");
#endif
        } break;

        case AppEvent::wifi_enabled: {
            m.flags.b.wifi_enabled = 1;
            m.display_request++;
        } break;

        case AppEvent::wifi_AP_not_found: {
#ifdef DISPLAY_STATE
            ESP_LOGE(TAG, "Error, AP \"%s\" not found!", m.cfg->get_ssid());
#endif
        } break;

        case AppEvent::wifi_disconnected: {
#ifdef DISPLAY_STATE
            ESP_LOGI(TAG, "Disconnected from Wifi AP \"%s\".", m.cfg->get_ssid());
#endif
        } break;

        case AppEvent::wifi_connected: {
#ifdef DISPLAY_STATE
            ESP_LOGI(TAG, "Connected to Wifi AP \"%s\".", m.cfg->get_ssid());
#endif
            m.flags.b.wifi_connected = 1;
            m.display_request++;

            esp_event_post(APP_EVENT, (int32_t)AppEvent::mqtt_configure, nullptr, 0, pdMS_TO_TICKS(1));
        } break;

        case AppEvent::driver_ready: {
            m.flags.b.driver_ready = 1;
            m.display_request++;

            if (m.sensor != nullptr) {
                m.sensor->set_driver(m.driver);
            } else {
                ESP_LOGE(TAG, "App.event: Driver ready. Fatal error, try to activate driver with no Sensor object!");
            }

            vTaskDelay(pdMS_TO_TICKS(500));
            esp_event_post(APP_EVENT, (int32_t)AppEvent::mqtt_configure, nullptr, 0, pdMS_TO_TICKS(1));
            esp_event_post(APP_EVENT, (int32_t)AppEvent::web_start_server, nullptr, 0, pdMS_TO_TICKS(1));
        } break;

        case AppEvent::web_start_server: {
            if ((m.flags.b.website_ready  == 0) && 
                (m.flags.b.wifi_connected == 1) && 
                (m.flags.b.driver_ready   == 1)) {
                m.webserver->start(this, m.station->get_ip());
            } else {
                vTaskDelay(pdMS_TO_TICKS(1000));
                esp_event_post(APP_EVENT, (int32_t)AppEvent::web_start_server, nullptr, 0, pdMS_TO_TICKS(1));
            }
        } break;

        case AppEvent::web_started: {
            m.flags.b.website_ready = 1;
            m.display_request++;
        } break;

        case AppEvent::mqtt_configure: {
#ifdef DISPLAY_STATE
            ESP_LOGI(TAG, "AppEvent::mqtt_configure");
#endif
            if ((m.flags.b.wifi_connected == 0) || (m.flags.b.driver_ready == 0)) {
#ifdef DISPLAY_STATE
                ESP_LOGI(TAG, "AppEvent::mqtt_configure: WiFi not ready, MQTT is shut down.");
#endif
                SAFE_DELETE(m.mqtt);
                break;
            }

            if (m.cfg->get_mqtt_enable()) {
#ifdef DISPLAY_STATE
                ESP_LOGI(TAG, "AppEvent::mqtt_configure: MQTT is enabled.");
#endif
                if (m.mqtt == nullptr) {
#ifdef DISPLAY_STATE
                    ESP_LOGI(TAG, "AppEvent::mqtt_configure: Create new MQTT manager.");
#endif
                    const char* broker = m.cfg->get_mqtt_broker();
                    if (strlen(broker) > 0) {
                        m.mqtt = new Mqtt(m.cfg->get_mqtt_broker(), m.cfg->get_mqtt_username(), m.cfg->get_mqtt_password());
                    }
                }
#ifdef DISPLAY_STATE
                ESP_LOGI(TAG, "AppEvent::mqtt_configure: MQTT startup.");
#endif
                m.mqtt->start(m.driver);
            } else {
#ifdef DISPLAY_STATE
                ESP_LOGI(TAG, "AppEvent::mqtt_configure: MQTT is disabled.");
#endif
                if (m.mqtt != nullptr) {
                    SAFE_DELETE(m.mqtt);
                }
            }
        } break;

        case AppEvent::web_time_sync: {
#ifdef DISPLAY_STATE
            ESP_LOGI(TAG, "Webserver time synchronization event.");
#endif
            reload_screensaver();
        } break;

        case AppEvent::nvm_update: {
            request_sys_config_update();
        } break;

        case AppEvent::factory_reset: {
            m.flags.b.factory_init_req = 1;
        } break;

        case AppEvent::reboot: {
            m.flags.b.reboot_req = 1;
        } break;

        case AppEvent::display_config: {
            m.flags.b.display_cfg_req = 1;
        } break;

        case AppEvent::led_config: {
            m.flags.b.led_cfg_req = 1;
        } break;

        case AppEvent::display_lock: {
            m.flags.b.display_lock = 1;
#ifdef DISPLAY_STATE
            ESP_LOGI(TAG, "Display lock SET event.");
#endif
        } break;

        case AppEvent::display_unlock: {
            m.flags.b.display_lock = 0;
#ifdef DISPLAY_STATE
            ESP_LOGI(TAG, "Display lock CLEAR event.");
#endif
        } break;

        case AppEvent::driver_config: {
            m.flags.b.driver_cfg_req = 1;
        } break;
        
        default: {
#ifdef DISPLAY_STATE
            ESP_LOGE(TAG, "Unsupported message %d.", (int)event_id);
#endif
        } break;

    }

    return (ESP_OK);
}

AppState App::run(void) {
    while (trigger_watchdog() == AppState::OK) {

        handle_config_changes();
        handle_nvm_update();
        handle_reboot_request();

        handle_LEDs();
        handle_display();
        handle_menu();

        vTaskDelay(pdMS_TO_TICKS(40));
    }
    return (AppState::OK);
}

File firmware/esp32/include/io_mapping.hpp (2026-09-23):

/*
 * ==============================================================================
 *
 *  PROJECT:     "Rase" Radio Sensor Project,    ESP32-S3 Station Device Firmware
 *  COPYRIGHT:   (C)2025-2026 KKS-Elektronik,  M. Kreck, <makreck@googlemail.com>
 *
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
 * ==============================================================================
 */

#pragma once


#ifdef ESP32_S3_WROOM_1

#define ESP32_BOOT_BUTTON       (GPIO_NUM_0)
#define ESP32_ALT_BUTTON1       (GPIO_NUM_14)
#define ESP32_ALT_BUTTON2       (GPIO_NUM_NC)

#define UDB_D_MINUS             (GPIO_NUM_20)
#define USB_D_PLUS              (GPIO_NUM_19)

#define BOOTLOADER_TXD_UART0    (GPIO_NUM_43)
#define BOOTLOADER_RXD_UART0    (GPIO_NUM_44)

#define SD_CARD_DATA            (GPIO_NUM_40)
#define SD_CARD_CLK             (GPIO_NUM_39)
#define SD_CARD_CMD             (GPIO_NUM_38)

#define CAM_SIOD                (GPIO_NUM_4)
#define CAM_SIOC                (GPIO_NUM_5)
#define CAM_VSYNC               (GPIO_NUM_6)
#define CAM_HREF                (GPIO_NUM_7)
#define CAM_XCLK                (GPIO_NUM_NC)
#define CAM_Y9                  (GPIO_NUM_16)
#define CAM_Y8                  (GPIO_NUM_17)
#define CAM_Y7                  (GPIO_NUM_18)
#define CAM_Y4                  (GPIO_NUM_8)
#define CAM_Y3                  (GPIO_NUM_9)
#define CAM_Y5                  (GPIO_NUM_10)
#define CAM_Y2                  (GPIO_NUM_11)
#define CAM_Y6                  (GPIO_NUM_12)
#define CAM_PCLK                (GPIO_NUM_13)

#define LED_DEVBOARD_PIN        (GPIO_NUM_2)
#define LED_NEOPIXEL            (GPIO_NUM_48)
#define RGBLED_PIN_R            (GPIO_NUM_NC)
#define RGBLED_PIN_G            (GPIO_NUM_NC)
#define RGBLED_PIN_B            (GPIO_NUM_NC)

#define DISPLAY_I2C_SDA         (GPIO_NUM_21)
#define DISPLAY_I2C_SCL         (GPIO_NUM_47)
#define DISPLAY_VCC             (GPIO_NUM_NC)
#define DISPLAY_GND             (GPIO_NUM_NC)

#define SENSOR_PORT_SDA         (GPIO_NUM_41)
#define SENSOR_PORT_SCL         (GPIO_NUM_42)
#define SENSOR_PORT_GND         (GPIO_NUM_NC)
#define SENSOR_PORT_VCC         (GPIO_NUM_NC)

#endif


#ifdef ESP32_S3_SUPER_MINI

#define ESP32_BOOT_BUTTON       (GPIO_NUM_18)
#define ESP32_ALT_BUTTON1       (GPIO_NUM_8)
#define ESP32_ALT_BUTTON2       (GPIO_NUM_NC)

#define UDB_D_MINUS             (GPIO_NUM_19)
#define USB_D_PLUS              (GPIO_NUM_20)

#define BOOTLOADER_TXD_UART0    (GPIO_NUM_NC) // direct pin, no GPIO
#define BOOTLOADER_RXD_UART0    (GPIO_NUM_NC) // direct pin, no GPIO

#define SD_CARD_DATA            (GPIO_NUM_NC)
#define SD_CARD_CLK             (GPIO_NUM_NC)
#define SD_CARD_CMD             (GPIO_NUM_NC)

#define LED_DEVBOARD_PIN        (GPIO_NUM_NC)
#define RGBLED_PIN_R            (GPIO_NUM_NC)
#define RGBLED_PIN_G            (GPIO_NUM_NC)
#define RGBLED_PIN_B            (GPIO_NUM_NC)
#define LED_NEOPIXEL            (GPIO_NUM_48)

#define DISPLAY_I2C_SDA         (GPIO_NUM_12)
#define DISPLAY_I2C_SCL         (GPIO_NUM_13)
#define DISPLAY_VCC             (GPIO_NUM_NC)
#define DISPLAY_GND             (GPIO_NUM_NC)

#define SENSOR_PORT_SDA         (GPIO_NUM_10)
#define SENSOR_PORT_SCL         (GPIO_NUM_11)
#define SENSOR_PORT_GND         (GPIO_NUM_NC)
#define SENSOR_PORT_VCC         (GPIO_NUM_NC)

#endif


#ifdef SEEED_XIAO_S3

#define ESP32_BOOT_BUTTON       (GPIO_NUM_1)
#define ESP32_ALT_BUTTON1       (GPIO_NUM_NC)
#define ESP32_ALT_BUTTON2       (GPIO_NUM_NC)

#define UDB_D_MINUS             (GPIO_NUM_19)
#define USB_D_PLUS              (GPIO_NUM_20)

#define BOOTLOADER_TXD_UART0    (GPIO_NUM_43)
#define BOOTLOADER_RXD_UART0    (GPIO_NUM_44)

#define SD_CARD_DATA            (GPIO_NUM_NC)
#define SD_CARD_CLK             (GPIO_NUM_NC)
#define SD_CARD_CMD             (GPIO_NUM_NC)

#define LED_DEVBOARD_PIN        (GPIO_NUM_21)
#define RGBLED_PIN_R            (GPIO_NUM_NC)
#define RGBLED_PIN_G            (GPIO_NUM_NC)
#define RGBLED_PIN_B            (GPIO_NUM_NC)
#define LED_NEOPIXEL            (GPIO_NUM_7)

#define DISPLAY_I2C_SDA         (GPIO_NUM_8)
#define DISPLAY_I2C_SCL         (GPIO_NUM_9)
#define DISPLAY_VCC             (GPIO_NUM_NC)
#define DISPLAY_GND             (GPIO_NUM_NC)

#define SENSOR_PORT_SDA         (GPIO_NUM_5)
#define SENSOR_PORT_SCL         (GPIO_NUM_44)
#define SENSOR_PORT_GND         (GPIO_NUM_NC)
#define SENSOR_PORT_VCC         (GPIO_NUM_NC)

#endif


#ifdef ESP32_S3_ZERO

#define ESP32_BOOT_BUTTON       (GPIO_NUM_0)
#define ESP32_ALT_BUTTON1       (GPIO_NUM_6)
#define ESP32_ALT_BUTTON2       (GPIO_NUM_5)

#define UDB_D_MINUS             (GPIO_NUM_19)
#define USB_D_PLUS              (GPIO_NUM_20)

#define BOOTLOADER_TXD_UART0    (GPIO_NUM_43)
#define BOOTLOADER_RXD_UART0    (GPIO_NUM_44)

#define SD_CARD_DATA            (GPIO_NUM_NC)
#define SD_CARD_CLK             (GPIO_NUM_NC)
#define SD_CARD_CMD             (GPIO_NUM_NC)
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

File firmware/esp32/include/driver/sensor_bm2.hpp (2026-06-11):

/*
 * ==============================================================================
 *
 *  PROJECT:     "Rase" Radio Sensor Project,    ESP32-S3 Station Device Firmware
 *  COPYRIGHT:   (C)2025-2026 KKS-Elektronik,  M. Kreck, <makreck@googlemail.com>
 *
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
 * ==============================================================================
 */

#pragma once

#define BM2_MSBLSB_TO_U16(msb, lsb) (((uint16_t)msb << 8) | ((uint16_t)lsb))

#define BM2_PRESSURE_TEMPERATURE_CALIB_DATA_LENGTH  (26)
#define BM2_HUMIDITY_CALIB_DATA_LENGTH              (7)
#define BM2_GEN_READ_WRITE_DATA_LENGTH              (1)
#define BM2_HUMIDITY_DATA_LENGTH                    (2)
#define BM2_TEMPERATURE_DATA_LENGTH                 (3)
#define BM2_PRESSURE_DATA_LENGTH                    (3)
#define BM2_ALL_DATA_FRAME_LENGTH                   (8)

#define	BM2_DATA_FRAME_PRESSURE_MSB_BYTE	    (0)
#define	BM2_DATA_FRAME_PRESSURE_LSB_BYTE		(1)
#define	BM2_DATA_FRAME_PRESSURE_XLSB_BYTE	    (2)
#define	BM2_DATA_FRAME_TEMPERATURE_MSB_BYTE	    (3)
#define	BM2_DATA_FRAME_TEMPERATURE_LSB_BYTE	    (4)
#define	BM2_DATA_FRAME_TEMPERATURE_XLSB_BYTE	(5)
#define	BM2_DATA_FRAME_HUMIDITY_MSB_BYTE		(6)
#define	BM2_DATA_FRAME_HUMIDITY_LSB_BYTE		(7)

#define	BM2_MASK_DIG_H4             (0x0F)

#define BMP280_CHIP_ID              (0x58)
#define BME280_CHIP_ID              (0x60)

#define BM2_I2C_ADDRESS1            (0x76)
#define BM2_I2C_ADDRESS2            (0x77)

#define BM2_SLEEP_MODE              (0x00)
#define BM2_FORCED_MODE             (0x01)
#define BM2_NORMAL_MODE             (0x03)

#define BM2_STANDBY_TIME_1_MS       (0x00)
#define BM2_STANDBY_TIME_63_MS      (0x01)
#define BM2_STANDBY_TIME_125_MS     (0x02)
#define BM2_STANDBY_TIME_250_MS     (0x03)
#define BM2_STANDBY_TIME_500_MS     (0x04)
#define BM2_STANDBY_TIME_1000_MS    (0x05)
#define BM2_STANDBY_TIME_10_MS      (0x06)
#define BM2_STANDBY_TIME_20_MS      (0x07)

#define BM2_OVERSAMP_SKIPPED        (0x00)
#define BM2_OVERSAMP_1X             (0x01)
#define BM2_OVERSAMP_2X             (0x02)
#define BM2_OVERSAMP_4X             (0x03)
#define BM2_OVERSAMP_8X             (0x04)
#define BM2_OVERSAMP_16X            (0x05)

#define BM2_FILTER_COEFF_OFF        (0x00)
#define BM2_FILTER_COEFF_2          (0x01)
#define BM2_FILTER_COEFF_4          (0x02)
#define BM2_FILTER_COEFF_8          (0x03)
#define BM2_FILTER_COEFF_16         (0x04)

#define BM2_SOFT_RESET_CODE             (0xB6)
#define BM2_SOFT_RESET_WAIT_TIME_MS     (3)
#define BM2_STANDARD_OVERSAMP_HUMIDITY	(BM2_OVERSAMP_1X)
#define BM2_INIT_VALUE                  (0)
#define BM2_CHIP_ID_READ_COUNT          (5)
#define BM2_INVALID_DATA                (0)


#define T_INIT_MAX                  (20)
#define T_MEASURE_PER_OSRS_MAX      (37)
#define T_SETUP_PRESSURE_MAX        (10)
#define T_SETUP_HUMIDITY_MAX        (10)

#define BM2_TEMPERATURE_DATA_SIZE   (3)
#define BM2_PRESSURE_DATA_SIZE      (3)
#define BM2_HUMIDITY_DATA_SIZE      (2)
#define BM2_DATA_FRAME_SIZE         (BM2_TEMPERATURE_DATA_SIZE + BM2_PRESSURE_DATA_SIZE + BM2_HUMIDITY_DATA_SIZE)

#define BM2_CALIBRATION_REG_BASE (0x88)

// BME280 register map:
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

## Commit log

2026-06-11 Initial commit.
    [OneGlasCradle-Glas.stl, OneGlasCradle-Plates.stl, OneGlasCradle.FCStd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]
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2026-06-17 No longer disable channel when sensor is disconnected, so the curves can still be displayed.
2026-06-17 LogFile must be handled in evaluation threads because time window may change during evaluation.
2026-06-21 Config interface modified. Prpared for sensor parametrisation.
2026-06-22 Added event driven factory-reset and reboot management.
    [app_main.cpp, events.hpp]
2026-06-22 Extended config interface and prevent from problems from reconfiguring JTAG interface while booting.
    [config_interface.cpp]
2026-06-24 Switched to relative curve coordinates.
2026-06-25 Matching length of device name with string in ProductID class.
2026-06-25 Added device ID data for each curve, since same nodes in different devices may have the same key.
2026-06-25 Added getter for device ID information.
2026-06-25 Added device ID to line recorder object finder result.
2026-06-25 Added channel count to sensor message.
2026-06-25 Added a channel count variable to SensorQuery structure.
2026-06-27 Improved evaluator initialization and added device serial number handling.
2026-06-29 Removed line recorder link from sensor widget.
2026-06-29 Added sensor widget link to sensor connection parameters.
2026-07-01 Added device node key scan function.
2026-07-01 Added get witched and get slot getters.
2026-07-02 Added MQTT broker config interface and optimized parsing.
    [config_interface.cpp]
2026-07-06 Added a value formatting according sensor properties.
2026-07-07 Added a modification flag to sensor reading class.
2026-07-08 Partition table recalculated.
    [huge_app.csv]
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2026-07-12 Set different MQTT client ID's for each device.
2026-07-12 Added a "max" value to sensor type list.
2026-07-16 Added IP-address to ID JSON frame.
2026-07-17 Corrected LED intensity value.
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2026-07-17 Fitted for new ID frame generation.
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2026-07-19 Added driver uninstall to config interface UART config.
2026-07-20 Extended class with device data related functions (moved from other modules).
2026-07-20 Removed device related functions.
2026-07-20 Changed calls to new device class methods.
2026-07-20 Added device config JSON formatter.
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2026-07-21 Extended device config functions.
2026-07-21 Moved sensor types string.
2026-07-23 Added firmware upload button and icon.
2026-07-23 Created a new segmented status line and an interval thread for interval tasks.
2026-07-24 Added driver config event.
2026-07-24 Config JSON extended by supported sensor types list.
2026-07-24 Dynamic sensor types list (from config JSON).
2026-07-24 Added I2C address getter.
2026-07-24 Switched menu op to new driver update.
2026-07-25 Splitted GUI file into menu, toolbar and dialog GUI files and extended device menu.
2026-07-25 Added more device menu functions.
2026-07-28 Created new EspTool class for ESP32 related access functions.
2026-07-28 Removed basic ESP32 related functions because moved to EspTool class.
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2026-07-30 Changed reset and initialization handling, Now always performed from the main thread only.
    [app.hpp, app_main.cpp]
2026-07-30 OTA upload now has its own thread.
2026-07-31 Added firmware test for another ESP32 type.
2026-07-31 Output in reboot functions relating to display rotation currently used.
    [app_main.cpp]
2026-08-01 Removed favicon slot from http server because not enough slots available.
2026-08-03 Switched website images to R-strings.
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2026-08-05 Incremented Retry for I2C device detect.
2026-08-06 Moved functions according device access methods to support later IP access.
2026-08-06 Implemented new device searching procedure.
2026-08-06 Added a mutex for accessing device list from multiple threads.
2026-08-06 Extended TTY device scan by multi-threading to improve speed.
2026-08-06 Added delete-device-list and updated destructor.
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2026-08-06 Implemented a thread for searching devices.
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2026-08-06 Device type selection changed.
2026-08-09 PLA Sensor Covers removed.
    [SeeedStudio_XIAO_ESP32S3_Housing.FCStd, SensorCover1.FCStd, SensorCover1.stl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]
2026-08-11 Added new ESP32-S3 type ESP32_S3_ALKS_MINI
2026-08-12 Update image support for 4th supported board added.
2026-08-13 Moved device updater into EspTool class, optimized it for static calls.
2026-08-13 Added reboot response on tty interface.
    [config_interface.cpp]
2026-08-18 Implemented multi-thread progress display for OTA updates.
2026-08-18 Implemented OTA update control thread and prepared for multi-device commands.
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2026-08-18 Do not reset boot flag.
    [app_main.cpp]
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2026-08-19 Tried SeeedStudio XIAO ESP32-S3 with PS-RAM usage.
2026-08-19 Board specific configurations refined, SPI-RAM enabled.
2026-08-19 New device ID fields inserted.
2026-08-20 Added new board type with ESP32-S2.
2026-08-20 Defined new board flags.
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2026-08-21 Moved board definition defaults into its own folder "boards".
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2026-08-21 Improved I2C OLED display performance and prepared for SSD1106 controller.
2026-08-21 Disabled cleanup before reboot.
    [app_main.cpp]
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2026-08-23 Fixed MQTT startup bug.
    [app_main.cpp]
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2026-09-01 Mechanical updates.
    [MT_Body_14500.stl, MT_Body_Batless.stl, MT_Display_Plate_Type_A.stl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]
2026-09-08 Images and housing updates.
    [MT_Body_Batless.stl, MT_Top_14500.stl, MT_Top_Batless.stl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]
2026-09-14 Housing updates.
    [MultiType_Housing_Rev_C.FCStd, OneGlasCradle.FCStd, SeeedStudio_XIAO_ESP32S3_Housing.FCStd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]
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2026-09-15 Added a little sleep time for preventing brown-out condition while powering up from a battery.
    [app.hpp, app_main.cpp]
2026-09-15 PSRAM settings for old ESP32 Wroom corrected.
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2026-09-17 Added dynamic color order assignment für Neopixel LEDs.
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2026-09-17 Added menu for defining the Neopixel LED color order.
2026-09-17 Added auto-update for LED color order config changes.
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2026-09-17 Updated config website with LED color order field.
2026-09-17 Updated config tool with new LED color order field.
2026-09-17 Power-up delay extended and using konstants instead of hardcoded values.
2026-09-20 Upesy Wrover DevKit V4 display pin update and prepared for I2C VCC GND on ports.
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

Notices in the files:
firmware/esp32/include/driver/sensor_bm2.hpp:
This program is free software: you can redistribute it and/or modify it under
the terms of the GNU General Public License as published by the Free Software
